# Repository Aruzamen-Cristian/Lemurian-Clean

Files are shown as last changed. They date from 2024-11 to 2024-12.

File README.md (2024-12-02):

# Lemurian Clean

### Descripción del Proyecto

Lemurian Clean es una solución autónoma y eficiente para la recogida de desechos en cuerpos de agua. Equipado con una cámara ESP-CAM y hélices para su movilidad, el robot navega por el agua recogiendo desechos con una cinta transportadora.

modelo3d (https://cdn.discordapp.com/attachments/764428029907697674/1312109408221921310/image.png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 "modelo3d")

### Características Principales

**Cámara ESP-CAM:** Proporciona capacidad de visión para la navegación y detección de desechos.

**Propulsión con Hélices:** Permite un movimiento eficiente y controlado en el agua.

**Cinta Transportadora:** Recolecta desechos desde la superficie del agua y los almacena en un contenedor interno.

### Hardware del Proyecto

-  **ESP32-CAM:** Proporciona capacidad de visión para la navegación y detección de desechos.

-  **ESP32:** Utiliza un ESP32 para controlar los drivers y motores del robot, asegurando una operación eficiente y precisa.

-  **Motores y Hélices:** Para la propulsión del robot.

- **Cinta Transportadora:** Para la recogida de basura.

- **Chasis y Carcasa:** Estructura resistente al agua y flotante.

### Código del Robot
Podes encontrar el código completo del robot en la carpeta `Codigo LC` del repositorio.

#### Función de Callback para Bluetooth

```c
void callback_function(esp_spp_cb_event_t event, esp_spp_cb_param_t *param) {
  if (event == ESP_SPP_START_EVT) {
    Serial.println("Inicializado SPP");
  } else if (event == ESP_SPP_SRV_OPEN_EVT) {
    Serial.println("Cliente conectado");
  } else if (event == ESP_SPP_CLOSE_EVT) {
    Serial.println("Cliente desconectado");
  } else if (event == ESP_SPP_DATA_IND_EVT) {
    Serial.println("Datos recibidos"); 
    while (BT.available()) {     // Mientras haya datos por recibir
      int incoming = BT.read();  // Lee un byte de los datos recibidos
    }
  }
}
```
> Explicacion:
Esta función maneja diferentes eventos del Bluetooth, como la inicialización, conexión y recepción de datos. Es crucial para interactuar con dispositivos Bluetooth.

#### Función setup()
```c
void setup() {
  Serial.begin(115200);     // Inicializando la conexión serial para debug
  BT.begin("ESP32_HOA");  // Nombre de tu Dispositivo Bluetooth y en modo esclavo
  Serial.println("El dispositivo Bluetooth está listo para emparejar");
  BT.register_callback(callback_function);  // Registramos la función "callback_function" como función callback.

  pinMode(Motor1a, OUTPUT);
  pinMode(Motor1b, OUTPUT);
  pinMode(Motor2a, OUTPUT);
  pinMode(Motor2b, OUTPUT);
	scale.begin(LOADCELL_DOUT_PIN, LOADCELL_SCK_PIN); 
	scale.set_scale(-471.497);
	scale.tare();
```
> Explicación:
> Inicialización Serial y Bluetooth: Se inicializa la comunicación serial para debug y la comunicación Bluetooth con el nombre "ESP32_HOA".
> Configuración de Pines: Se configuran los pines de los motores como salidas.
> Inicialización del Sensor: Se inicializa el sensor de celda de carga y se calibra la escala.

#### Función loop()
```c
void loop() {
  if (BT.available())  // Compruebe si recibimos algo de Bluetooth
  {
    int incoming = BT.read();  // Lee lo que recibimos
    Serial.print("Recibido: ");
    Serial.println(incoming);
    switch (incoming) {
      case 70:  // F en ASCII
        Adelante();
        break;
      case 66:  // B en ASCII
        Retroceder();
        break;
      case 76:     // L en ASCII
        Izquierda();
        break;
      case 82:  // R en ASCII
        Derecha();
        break;
      case 40:
        Serial.print("Primer Lectura:\t");
        Serial.print(scale.get_units(), 1);
        scale.power_down();
        scale.power_up();
        break;
      case 48:  // Velocidad 0
        veloc = 0;
        break;
      case 49:  // Velocidad 1
        veloc = 25;
        break;
      // Otros casos para velocidades
      default:
        Parar();
        break;
    }
  }
}

```
> Explicación:
Recepción de Comandos: La función `loop()` verifica si se han recibido datos por Bluetooth y actúa según el comando recibido. Dependiendo del comando, se ejecutan funciones para mover el robot hacia adelante, atrás, izquierda, derecha, o detenerse.

#### Funciones de Control de Motores
```c
void Adelante() {
  digitalWrite(Motor1a, HIGH);
  digitalWrite(Motor1b, LOW);
  digitalWrite(Motor2a, HIGH);
  digitalWrite(Motor2b, LOW);
}
void Retroceder() {
  digitalWrite(Motor1a, LOW);
  digitalWrite(Motor1b, HIGH);
  digitalWrite(Motor2a, LOW);
  digitalWrite(Motor2b, HIGH);
}
void Izquierda() {
  digitalWrite(Motor1a, LOW);
  digitalWrite(Motor1b, HIGH);
  digitalWrite(Motor2a, HIGH);
  digitalWrite(Motor2b, LOW);
}
void Derecha() {
  digitalWrite(Motor1a, HIGH);
  digitalWrite(Motor1b, LOW);
  digitalWrite(Motor2a, LOW);
  digitalWrite(Motor2b, HIGH);
}
void Parar() {
  digitalWrite(Motor1a, LOW);
  digitalWrite(Motor1b, LOW);
  digitalWrite(Motor2a, LOW);
  digitalWrite(Motor2b, LOW);
}

```

> Explicación:
Control de Motores: Estas funciones controlan la dirección de los motores para mover el robot hacia adelante, atrás, izquierda, derecha, o detenerlo. Usan `digitalWrite()`para cambiar el estado de los pines.

### Diseño del PCB
Los archivos del diseño del PCB están ubicados en la carpeta `PCB`. Puedes descargar los archivos y el diagrama esquemático para fabricar y ensamblar tu propia placa.

vdd
> PCBv4 Capa Superior


> PCBv4 Capa Inferior

### Uso
1. Encender el robot y asegurarse de que todos los sistemas están operativos.

3. Colocar el robot en el agua y activarlo.

5. Supervisar su operación a través de la cámara ESP-CAM y ajustar si es necesario.

#### Contacto
Para más información o preguntas sobre Lemurian Clean, puedes contactarnos en [ aruzamencristianmarcelo@gmail.com ], [damian34casas@gmail.com].

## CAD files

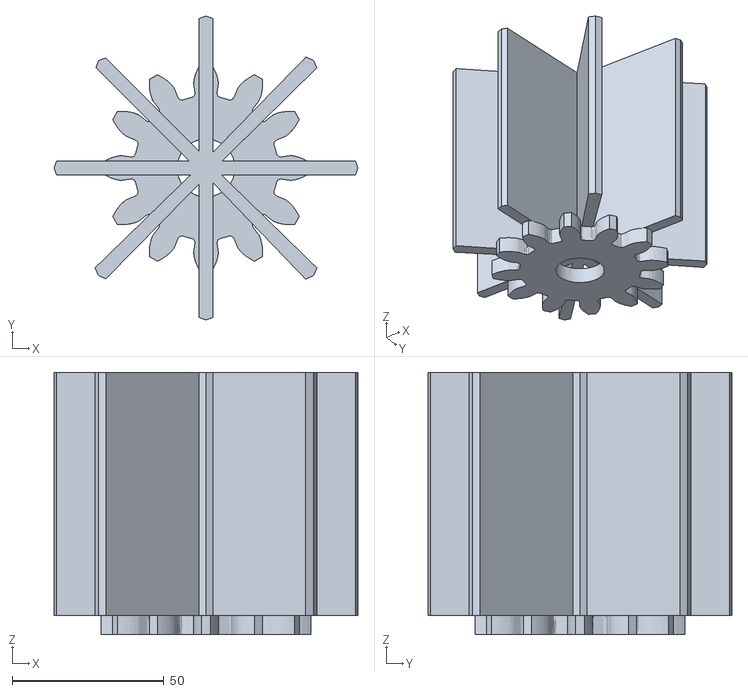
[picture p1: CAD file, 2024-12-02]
Modelo3D-LC/Engranaje 2.stl
100.0 x 100.0 x 86.2

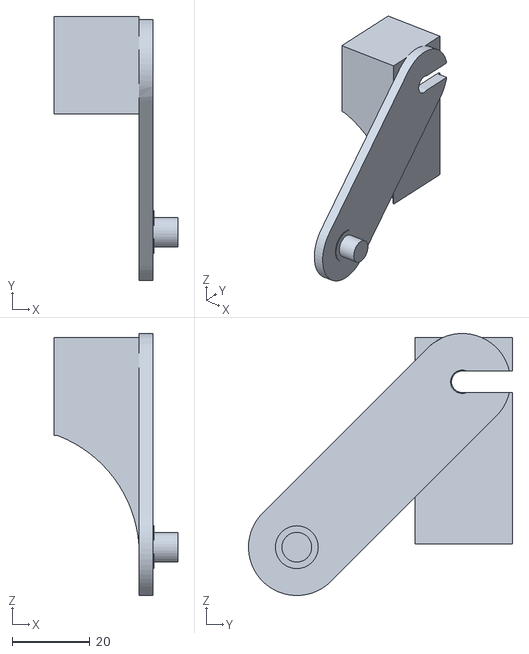
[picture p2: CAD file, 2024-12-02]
Modelo3D-LC/Soporte Motor 3.stl
31.7 x 67.7 x 67.2

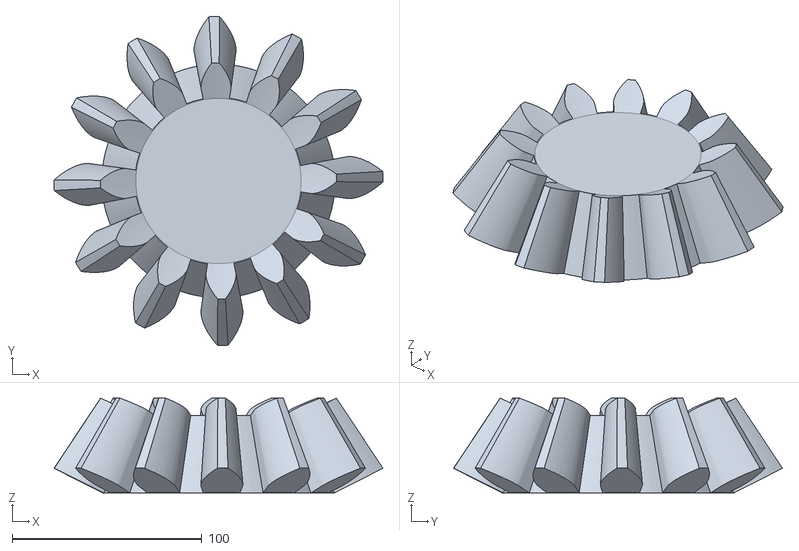
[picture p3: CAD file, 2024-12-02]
Modelo3D-LC/Aquatic Thrasher.stl
173.6 x 173.6 x 50.0

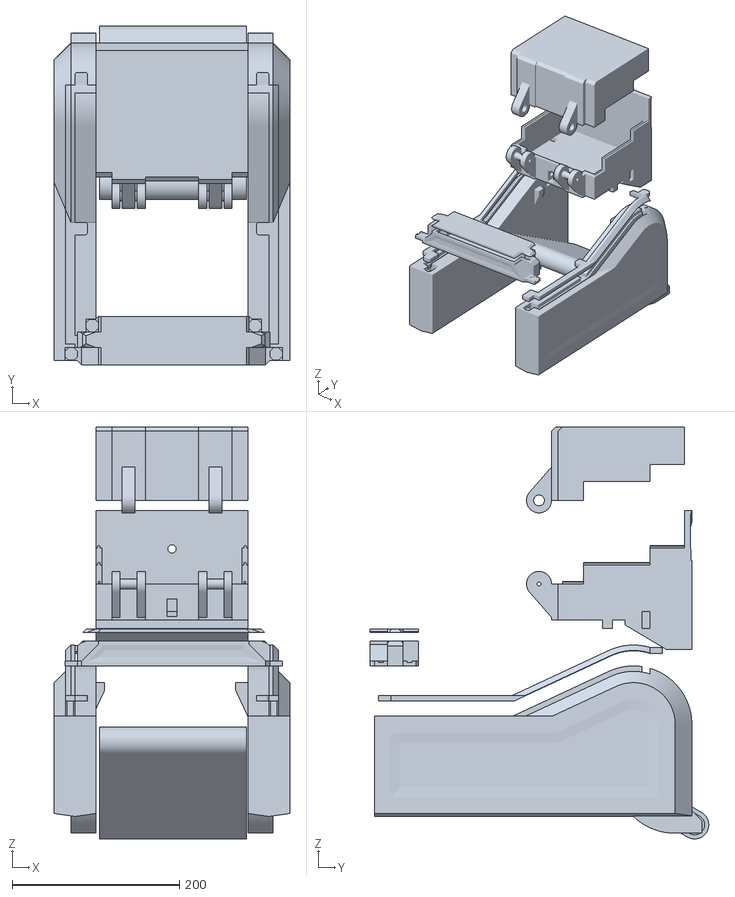
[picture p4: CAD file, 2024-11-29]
Modelo3D-LC/Modelo3D-LC.stl
282.0 x 405.2 x 493.0

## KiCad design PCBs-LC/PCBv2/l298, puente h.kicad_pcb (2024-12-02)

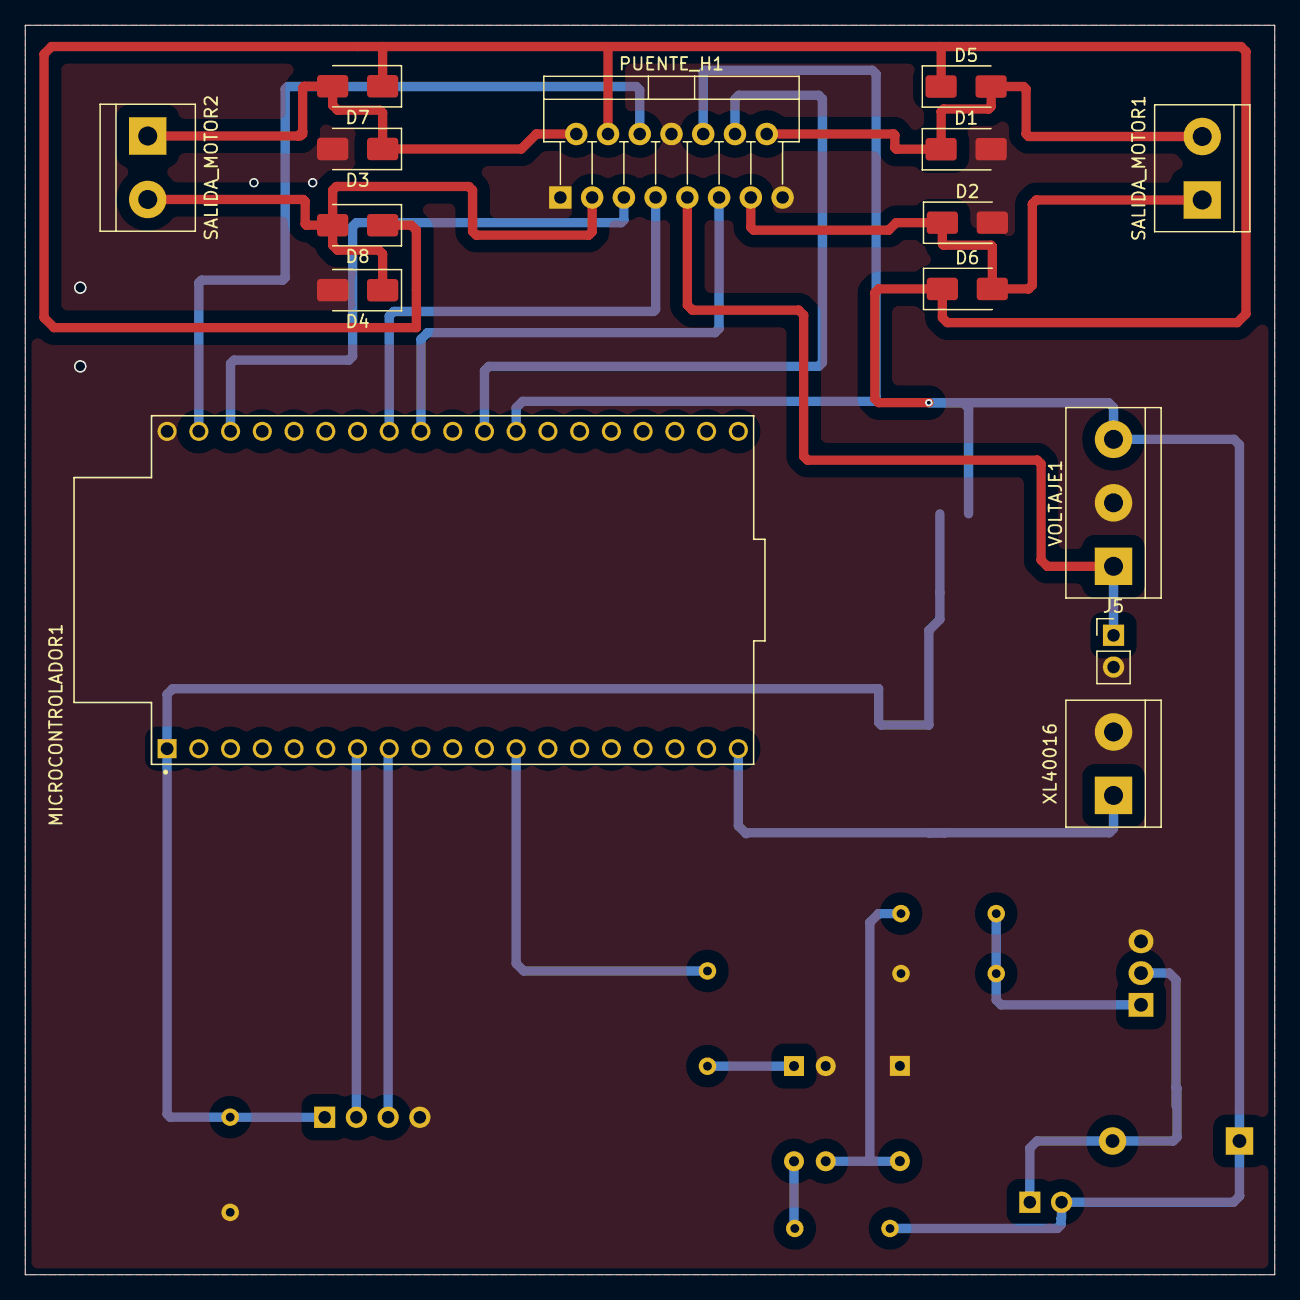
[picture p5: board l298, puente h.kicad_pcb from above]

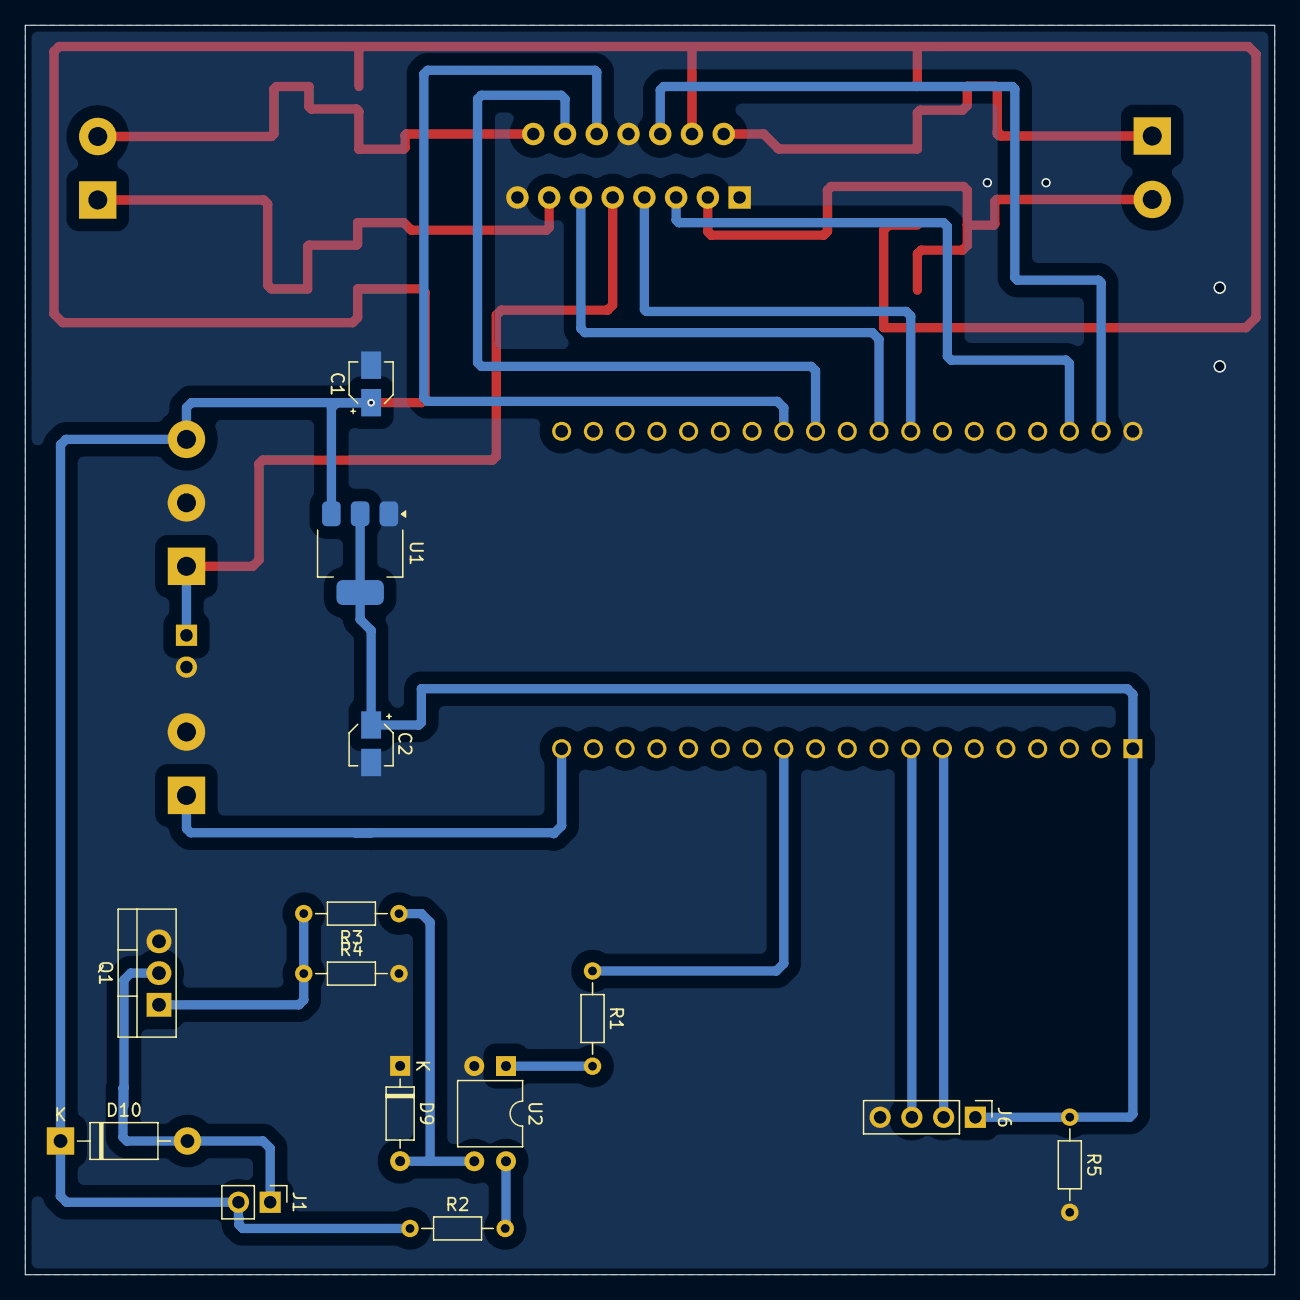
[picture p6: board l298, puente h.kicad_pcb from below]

Board: 2 copper layers, 100.0 x 100.0 mm, 29 parts (14 on the bottom side), 23 nets.

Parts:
C1, C2: 220; CP_Elec_3x5.3
D1, D2, D3, D4, D5, D6, D7, D8: 1N4148WT; D_SMA
D9: 1N4148; D_DO-35_SOD27_P7.62mm_Horizontal
D10: 1N4007; D_DO-41_SOD81_P10.16mm_Horizontal
J1: MOTOR_CINTA; PinHeader_1x02_P2.54mm_Vertical
J5: PinHeader_1x02_P2.54mm_Vertical
J6: PinHeader_1x04_P2.54mm_Vertical
MICROCONTROLADOR1: ESP32_DEVKITC; MODULE_ESP32-DEVKITC
PUENTE_H1: L298N; TO-220-15_P2.54x2.54mm_StaggerOdd_Lead4.58mm_Vertical
Q1: IRF540N; TO-220-3_Vertical
R1: 1K; R_Axial_DIN0204_L3.6mm_D1.6mm_P7.62mm_Horizontal
R2, R4: 4,7K; R_Axial_DIN0204_L3.6mm_D1.6mm_P7.62mm_Horizontal
R3: 100; R_Axial_DIN0204_L3.6mm_D1.6mm_P7.62mm_Horizontal
R5: 1k; R_Axial_DIN0204_L3.6mm_D1.6mm_P7.62mm_Horizontal
SALIDA_MOTOR1, SALIDA_MOTOR2: TerminalBlock_bornier-2_P5.08mm
U1: AMS1117; SOT-223-3_TabPin2
U2: PC817; DIP-4_W7.62mm
VOLTAJE1: TerminalBlock_bornier-3_P5.08mm
XL40016: TerminalBlock_bornier-2_P5.08mm

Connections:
3,3V: C2.1, J6.1, MICROCONTROLADOR1.1 (3V3), R5.1, U1.2 (VO)
+5V: J5.1, PUENTE_H1.9 (Vss), VOLTAJE1.1
+12V: C1.1, D5.1 (K), D6.1 (K), D7.1 (K), D8.1 (K), D10.1 (K), J1.2, PUENTE_H1.4 (Vs), R2.1, U1.3 (VI), VOLTAJE1.3
DT: J6.2, MICROCONTROLADOR1.7 (IO32)
EnA: MICROCONTROLADOR1.37 (IO23), PUENTE_H1.6 (EnA)
EnB: MICROCONTROLADOR1.30 (IO18), PUENTE_H1.11 (EnB)
GND: C1.2, C2.2, D1.2 (A), D2.2 (A), D3.2 (A), D4.2 (A), D9.1 (K), J5.2, J6.4, MICROCONTROLADOR1.38 (GND), PUENTE_H1.1 (SENSE_A), PUENTE_H1.8 (GND), PUENTE_H1.15 (SENSE_B), Q1.3 (S), R4.2, R5.2, U1.1 (ADJ), U2.2, VOLTAJE1.2, XL40016.2
IN1: MICROCONTROLADOR1.36 (IO22), PUENTE_H1.5 (IN1)
IN2: MICROCONTROLADOR1.31 (IO19), PUENTE_H1.7 (IN2)
IN3: MICROCONTROLADOR1.27 (IO16), PUENTE_H1.10 (IN3)
IN4: MICROCONTROLADOR1.28 (IO17), PUENTE_H1.12 (IN4)
unnamed: D9.2 (A), R3.1, U2.3
unnamed: D10.2 (A), J1.1, Q1.2 (D)
unnamed: Q1.1 (G), R3.2, R4.1
unnamed: R1.2, U2.1
unnamed: R2.2, U2.4
OUT1: D3.1 (K), D7.2 (A), PUENTE_H1.2 (OUT1), SALIDA_MOTOR2.1
OUT2: D4.1 (K), D8.2 (A), PUENTE_H1.3 (OUT2), SALIDA_MOTOR2.2
OUT3: D2.1 (K), D6.2 (A), PUENTE_H1.13 (OUT3), SALIDA_MOTOR1.1
OUT4: D1.1 (K), D5.2 (A), PUENTE_H1.14 (OUT4), SALIDA_MOTOR1.2
PWM: MICROCONTROLADOR1.12 (IO14), R1.1
SCK: J6.3, MICROCONTROLADOR1.8 (IO33)
Vin: MICROCONTROLADOR1.19 (5V), XL40016.1

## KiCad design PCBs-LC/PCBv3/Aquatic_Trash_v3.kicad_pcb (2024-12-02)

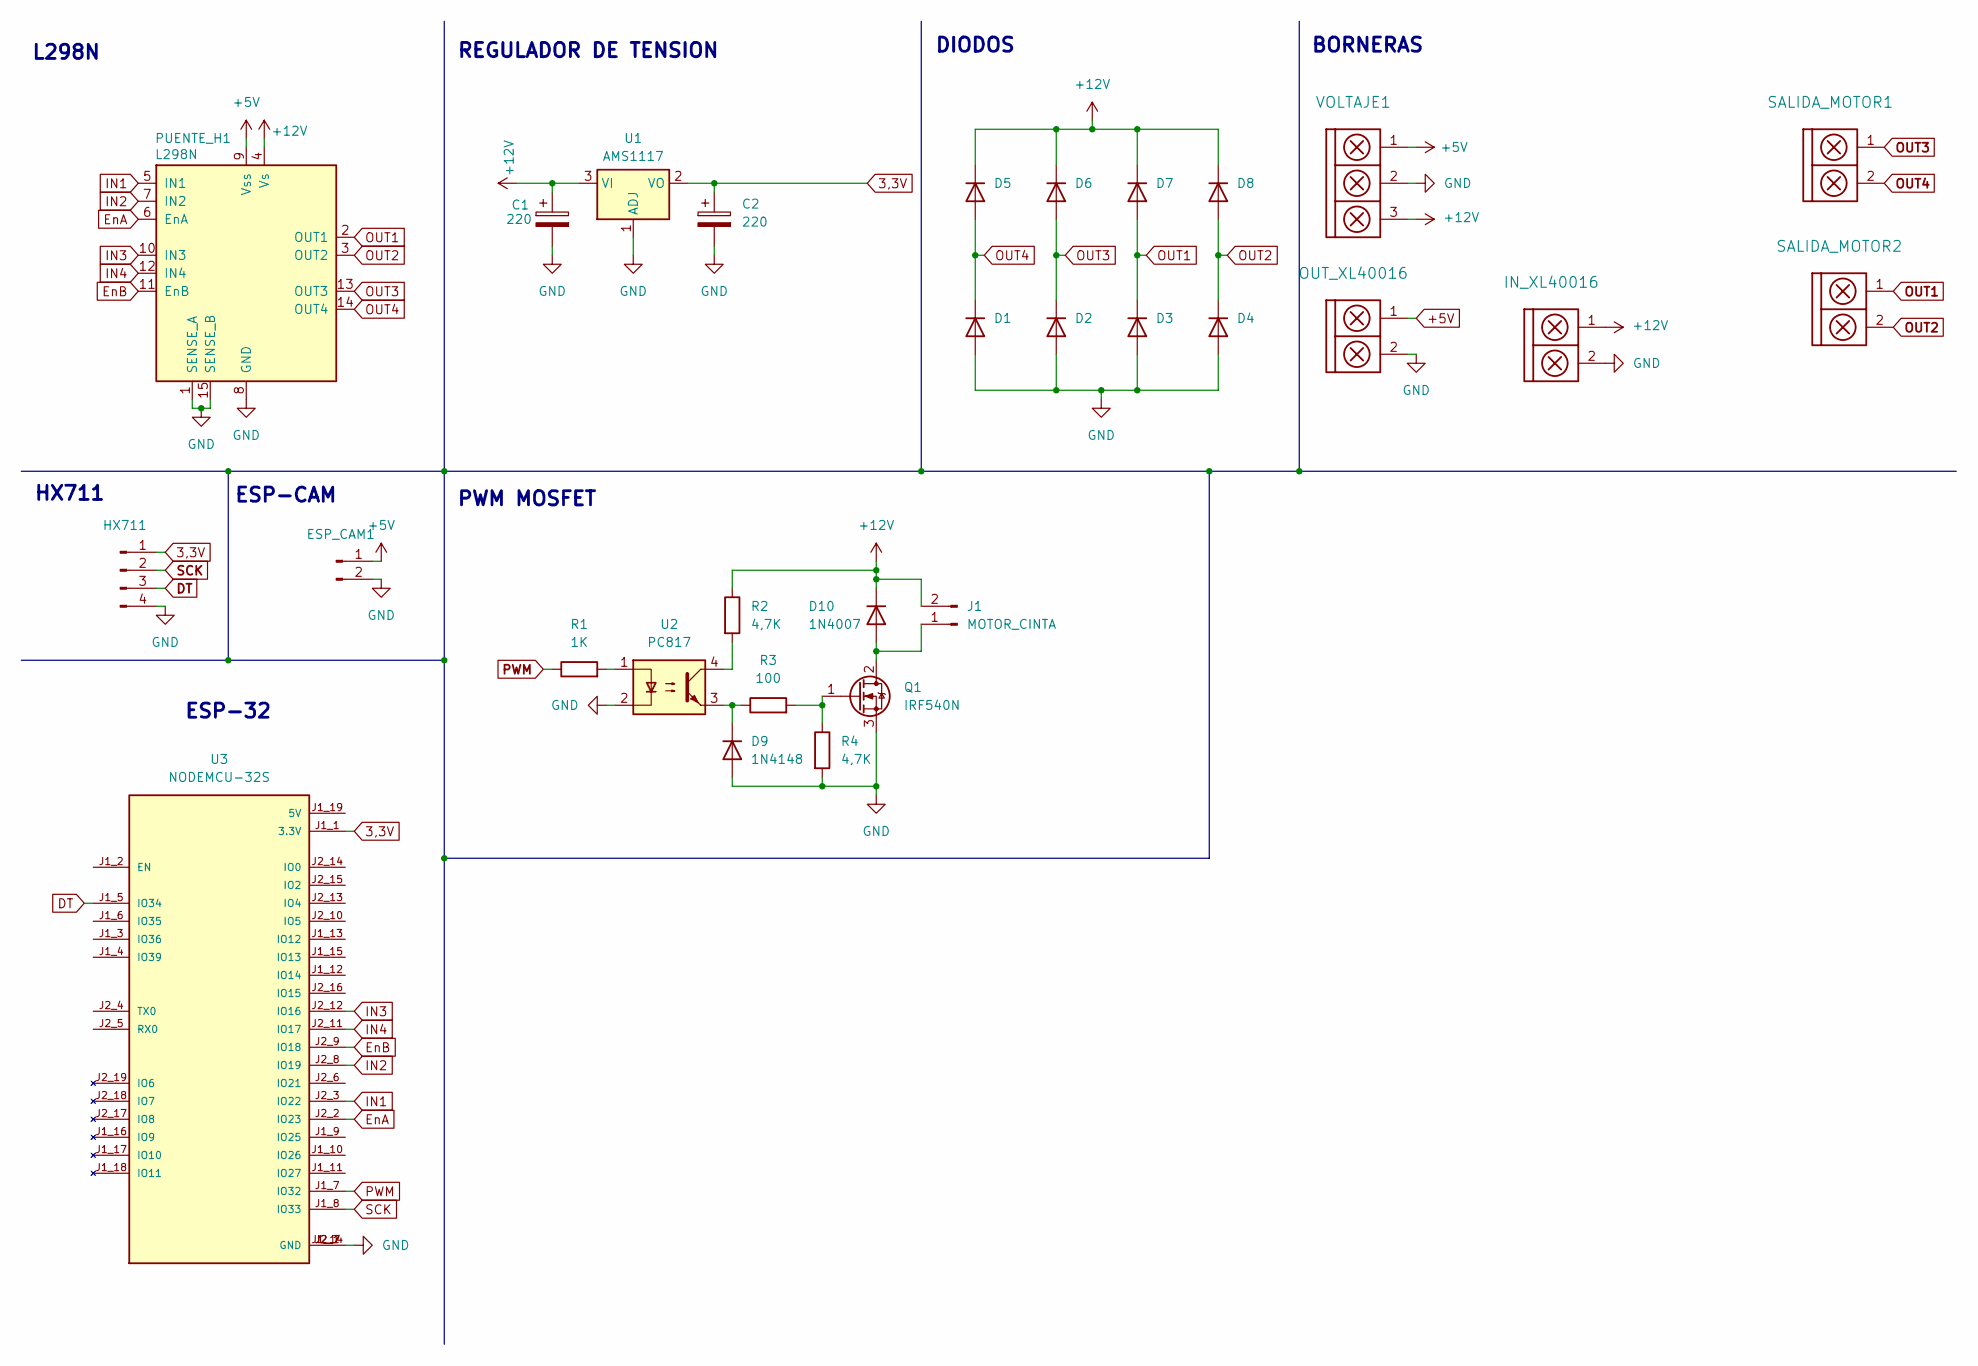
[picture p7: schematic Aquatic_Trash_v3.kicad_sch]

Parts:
C1, C2: 220; CP_Elec_8x10.5
D1, D2, D3, D4, D5, D6, D7, D8: 1N4148WT; D_SMA
D9: 1N4148; D_SMA
D10: 1N4007; D_SMA
ESP_CAM1: PinHeader_1x02_P2.54mm_Vertical
HX711: PinHeader_1x04_P2.54mm_Vertical
IN_XL40016: TerminalBlock_bornier-2_P5.08mm
J1: MOTOR_CINTA; PinHeader_1x02_P2.54mm_Vertical
OUT_XL40016: TerminalBlock_bornier-2_P5.08mm
PUENTE_H1: L298N; TO-220-15_P2.54x2.54mm_StaggerOdd_Lead4.58mm_Vertical
Q1: IRF540N; TO-220-3_Vertical
R1: 1K; R_0805_2012Metric
R2, R4: 4,7K; R_0805_2012Metric
R3: 100; R_0805_2012Metric
SALIDA_MOTOR1, SALIDA_MOTOR2: TerminalBlock_bornier-2_P5.08mm
U1: AMS1117; SOT-223-3_TabPin2
U2: PC817; DIP-4_W7.62mm
U3: NODEMCU-32S; MODULE_NODEMCU-32S; PARTREV V1
VOLTAJE1: TerminalBlock_bornier-3_P5.08mm

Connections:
3,3V: C2.1, HX711.1, U1.2 (VO), U3.J1_1 (3.3V)
+5V: ESP_CAM1.1, OUT_XL40016.1, PUENTE_H1.9 (Vss), U3.J1_19 (5V), VOLTAJE1.1
+12V: C1.1, D5.1 (K), D6.1 (K), D7.1 (K), D8.1 (K), D10.1 (K), IN_XL40016.1, J1.2, PUENTE_H1.4 (Vs), R2.1, U1.3 (VI), VOLTAJE1.3
DT: HX711.3, U3.J1_5 (IO34)
EnA: PUENTE_H1.6 (EnA), U3.J2_2 (IO23)
EnB: PUENTE_H1.11 (EnB), U3.J2_9 (IO18)
GND: C1.2, C2.2, D1.2 (A), D2.2 (A), D3.2 (A), D4.2 (A), D9.2 (A), ESP_CAM1.2, HX711.4, IN_XL40016.2, OUT_XL40016.2, PUENTE_H1.1 (SENSE_A), PUENTE_H1.8 (GND), PUENTE_H1.15 (SENSE_B), Q1.3 (S), R4.2, U1.1 (ADJ), U2.2, U3.J1_14 (GND), U3.J2_1 (GND), U3.J2_7 (GND), VOLTAJE1.2
IN1: PUENTE_H1.5 (IN1), U3.J2_3 (IO22)
IN2: PUENTE_H1.7 (IN2), U3.J2_8 (IO19)
IN3: PUENTE_H1.10 (IN3), U3.J2_12 (IO16)
IN4: PUENTE_H1.12 (IN4), U3.J2_11 (IO17)
unnamed: D9.1 (K), R3.1, U2.3
unnamed: D10.2 (A), J1.1, Q1.2 (D)
unnamed: Q1.1 (G), R3.2, R4.1
unnamed: R1.2, U2.1
unnamed: R2.2, U2.4
OUT1: D3.1 (K), D7.2 (A), PUENTE_H1.2 (OUT1), SALIDA_MOTOR2.1
OUT2: D4.1 (K), D8.2 (A), PUENTE_H1.3 (OUT2), SALIDA_MOTOR2.2
OUT3: D2.1 (K), D6.2 (A), PUENTE_H1.13 (OUT3), SALIDA_MOTOR1.1
OUT4: D1.1 (K), D5.2 (A), PUENTE_H1.14 (OUT4), SALIDA_MOTOR1.2
PWM: R1.1, U3.J1_7 (IO32)
SCK: HX711.2, U3.J1_8 (IO33)

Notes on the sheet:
HX711
REGULADOR DE TENSION
DIODOS
PWM MOSFET
BORNERAS
L298N
ESP-CAM
ESP-32

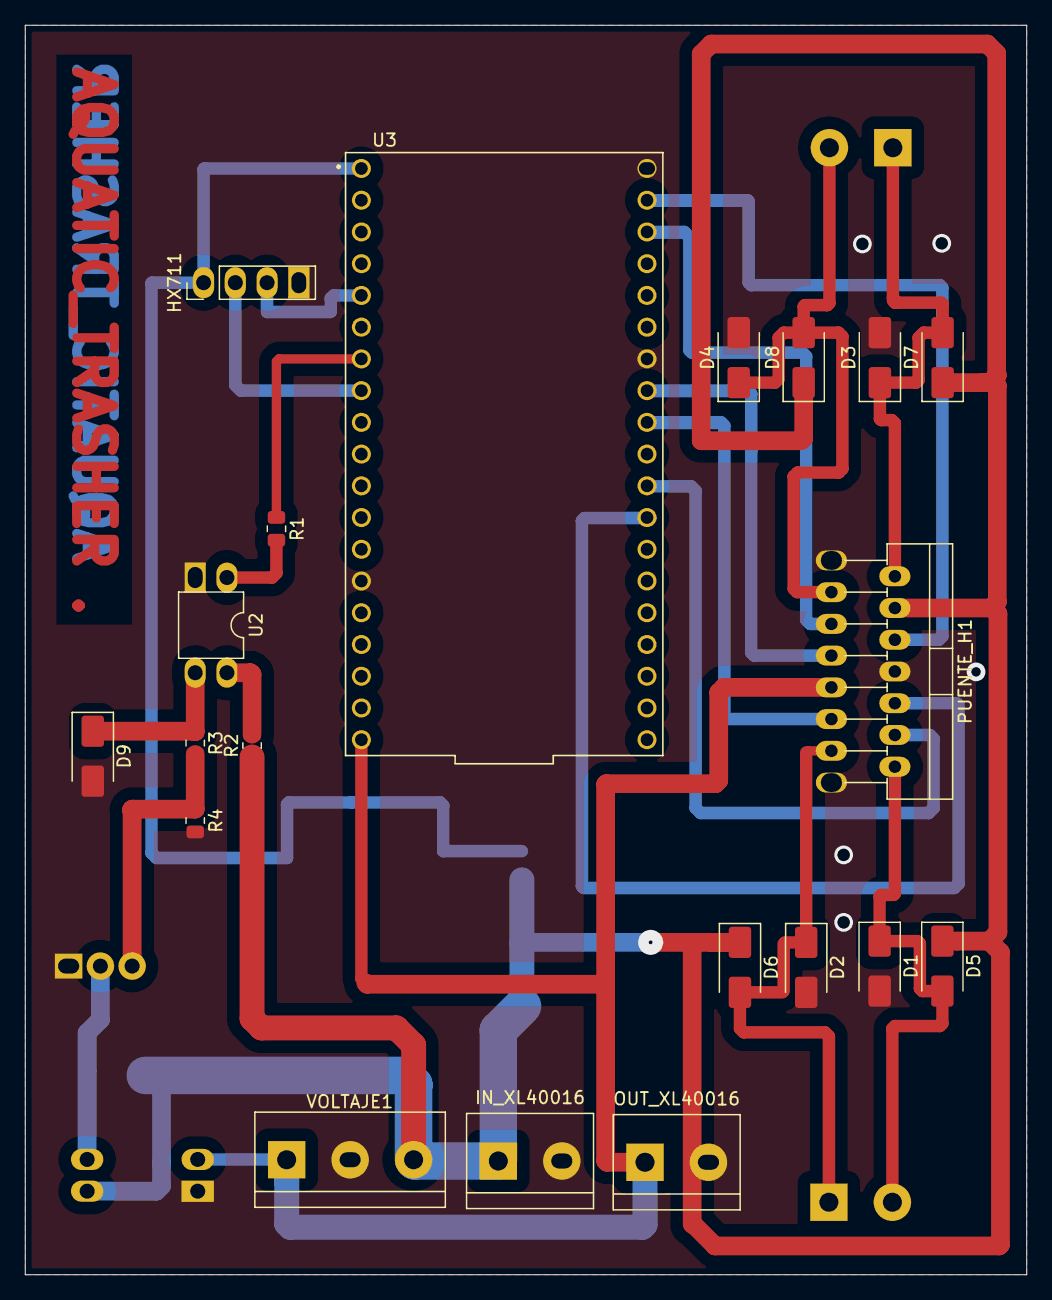
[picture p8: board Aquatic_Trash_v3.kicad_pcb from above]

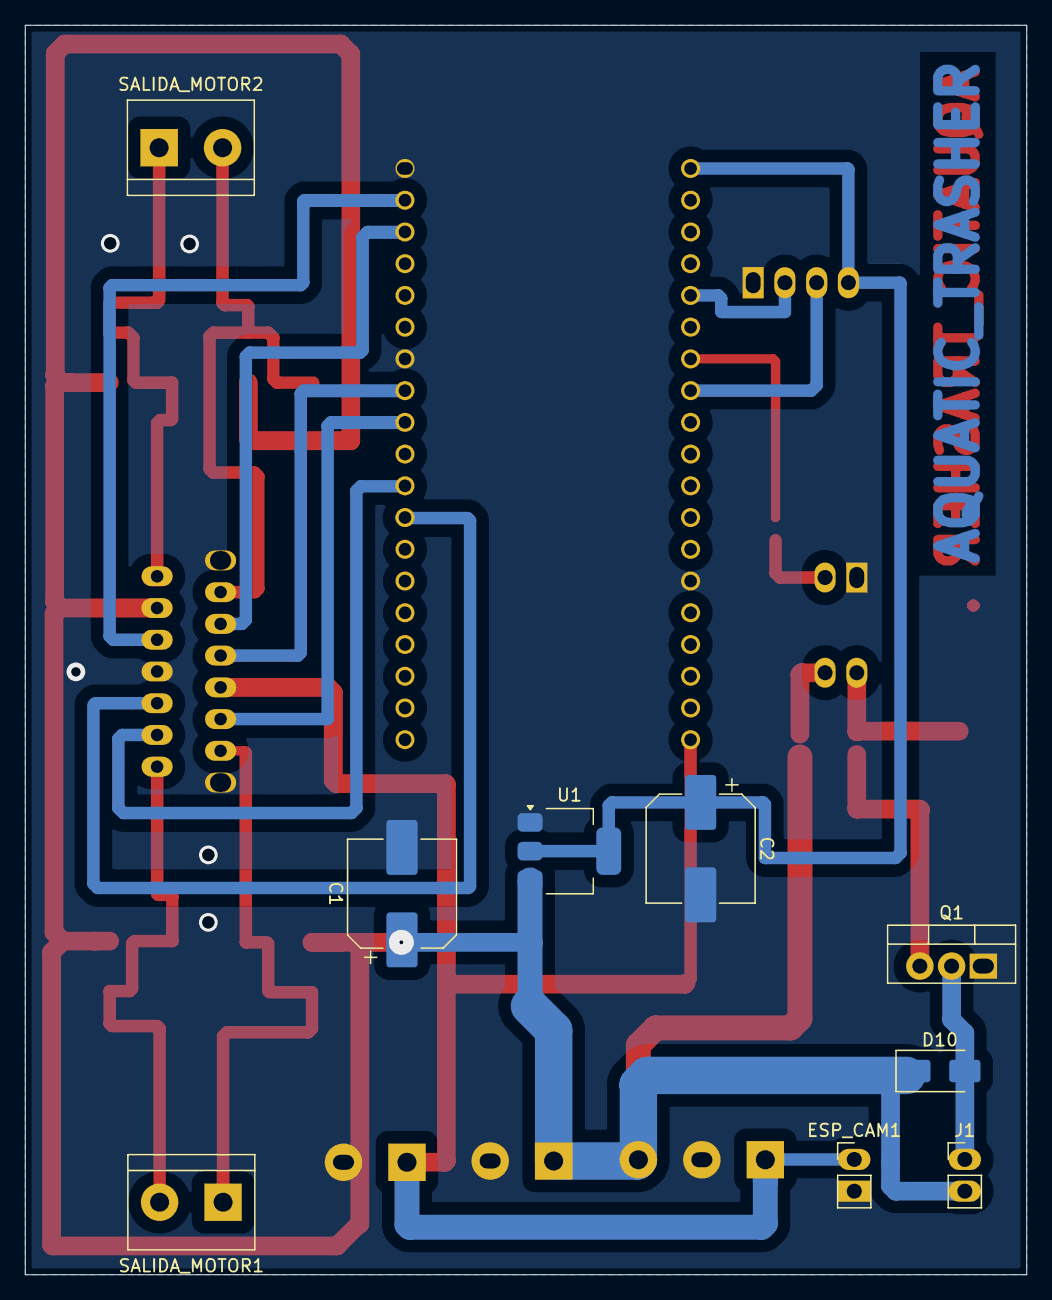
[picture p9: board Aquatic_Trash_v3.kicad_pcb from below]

Board: 2 copper layers, 80.2 x 100.0 mm, 29 parts (9 on the bottom side), 22 nets.

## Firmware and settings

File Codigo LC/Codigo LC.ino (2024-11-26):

#include <Arduino.h>
#include "HX711.h"
#include "soc/rtc.h"
#include "BluetoothSerial.h"
#if !defined(CONFIG_BT_ENABLED) || !defined(CONFIG_BLUEDROID_ENABLED)
#error Bluetooth no esta disponible!
#endif

#define Motor1a 32
#define Motor1b 33
#define Motor2a 25
#define Motor2b 26
const int LOADCELL_DOUT_PIN = 19;
const int LOADCELL_SCK_PIN = 18; 
int veloc;
HX711 scale;
BluetoothSerial BT;  // Objeto Bluetooth

void callback_function(esp_spp_cb_event_t event, esp_spp_cb_param_t *param) {
  if (event == ESP_SPP_START_EVT) {
    Serial.println("Inicializado SPP");
  } else if (event == ESP_SPP_SRV_OPEN_EVT) {
    Serial.println("Cliente conectado");
  } else if (event == ESP_SPP_CLOSE_EVT) {
    Serial.println("Cliente desconectado");
  } else if (event == ESP_SPP_DATA_IND_EVT) {
    Serial.println("Datos recibidos"); 
    while (BT.available()) {     // Mientras haya datos por recibir
      int incoming = BT.read();  // Lee un byte de los datos recibidos
    }
  }
}
void setup() {
  Serial.begin(115200);     // Inicializando la conexión serial para debug
  BT.begin("ESP32_HOA");  // Nombre de tu Dispositivo Bluetooth y en modo esclavo
  Serial.println("El dispositivo Bluetooth está listo para emparejar");
  BT.register_callback(callback_function);  // Registramos la función "callback_function" como función callback.

  pinMode(Motor1a, OUTPUT);
  pinMode(Motor1b, OUTPUT);
  pinMode(Motor2a, OUTPUT);
  pinMode(Motor2b, OUTPUT);
  
  Serial.println("HX711 Demo");

  Serial.println("Inicializando lectura");

  scale.begin(LOADCELL_DOUT_PIN, LOADCELL_SCK_PIN);

  Serial.println("Lectura de escala:");
  Serial.print("Lectura Escala: \t\t");
  Serial.println(scale.read());

  Serial.print("Lectura Promedio: \t\t");
  Serial.println(scale.read_average(20));

  Serial.print("Valores obtenidos: \t\t");
  Serial.println(scale.get_value(5));

  Serial.print("Unidades obtenidas: \t\t");
  Serial.println(scale.get_units(5), 1);
            
  scale.set_scale(-471.497);
  scale.tare();

  Serial.println("Despues de configurada la escala:");

  Serial.print("Lectura base: \t\t");
  Serial.println(scale.read());

  Serial.print("Lectura Promedio: \t\t");
  Serial.println(scale.read_average(20));

  Serial.print("Valor obtenido: \t\t");
  Serial.println(scale.get_value(5));

  Serial.print("Unidades obtenidas: \t\t");
  Serial.println(scale.get_units(5), 1);
  Serial.println("Lecturas:");
}
void loop() {
  if (BT.available())  // Compruebe si recibimos algo de Bluetooth
  {
    int incoming = BT.read();  // Lee lo que recibimos
    Serial.print("Recibido: ");
    Serial.println(incoming);
    Serial.print("\n");
    switch (incoming) {

      case 70:  // F en ASCII
        Adelante();
        Serial.print("Adelante \n");
        break;

      case 66:  // B en ASCII
        Retroceder();
        Serial.print("Retroceder \n");
        break;

      case 76:     // L en ASCII
        Izquierda();
        Serial.print("Izquierda \n");
        break;

      case 82:  // R en ASCII
        Derecha();
        Serial.print("Derecha \n");
        break;

      case 40:
        Serial.print("Primer Lectura:\t");
        Serial.print(scale.get_units(), 1);
        Serial.print("\t| promedio:\t");
        Serial.println(scale.get_units(10), 5);
        scale.power_down();
        scale.power_up();
        break;

      case 48:  // Velocidad 0
        veloc = 0;
        break;
      case 49:  // Velocidad 1
        veloc = 25;
        break;
      case 50:  // Velocidad 2
        veloc = 51;
        break;
      case 51:  // Velocidad 3
        veloc = 76;
        break;
      case 52:  // Velocidad 4
        veloc = 102;
        break;
      case 53:  // Velocidad 5
        veloc = 127;
        break;
      case 54:  // Velocidad 6
        veloc = 153;
        break;
      case 55:  // Velocidad 7
        veloc = 179;
        break;
      case 56:  // Velocidad 8
        veloc = 200;
        break;
      case 57:  // Velocidad 9
        veloc = 225;
        break;
      case 113:  // q en ASCII
        veloc = 255;
        break;
      default:
        Parar();
        Serial.print("Parado \n");
        break;
    }
  }
}
void Adelante() {

  digitalWrite(Motor1a, HIGH);
  digitalWrite(Motor1b, LOW);
  digitalWrite(Motor2a, HIGH);
  digitalWrite(Motor2b, LOW);
}
void Retroceder() {

  digitalWrite(Motor1a, LOW);
  digitalWrite(Motor1b, HIGH);
  digitalWrite(Motor2a, LOW);
  digitalWrite(Motor2b, HIGH);
}
void Izquierda() {

  digitalWrite(Motor1a, LOW);
  digitalWrite(Motor1b, HIGH);
  digitalWrite(Motor2a, HIGH);
  digitalWrite(Motor2b, LOW);
}
void Derecha() {

  digitalWrite(Motor1a, HIGH);
  digitalWrite(Motor1b, LOW);
  digitalWrite(Motor2a, LOW);
  digitalWrite(Motor2b, HIGH);
}
void Parar() {
  digitalWrite(Motor1a, LOW);
  digitalWrite(Motor1b, LOW);
  digitalWrite(Motor2a, LOW);
  digitalWrite(Motor2b, LOW);
}

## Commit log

2024-11-29 Añade PCB
    [aquatic _v5_final_ojala_que_si.kicad_pcb, aquatic _v5_final_ojala_que_si.kicad_sch]
2024-12-02 upload PBCs
    [Aquatic_Trash_v3.kicad_pcb, Aquatic_Trash_v3.kicad_sch, Aquatic_Trash_v4.kicad_pcb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]
2024-12-02 Upload 3dmodels
    [Aquatic Thrasher.stl, Engranaje 2.stl, Soporte Motor 3.stl]
